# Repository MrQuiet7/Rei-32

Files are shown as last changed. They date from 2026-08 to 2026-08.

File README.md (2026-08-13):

<p align="center">
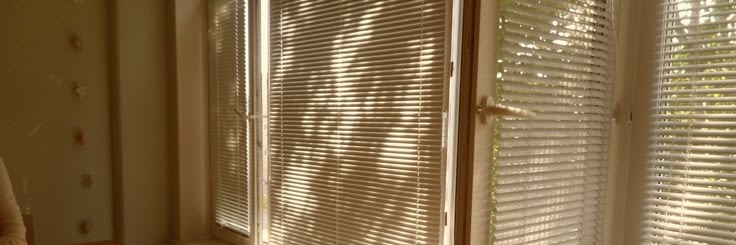
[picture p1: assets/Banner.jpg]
‌Banner
  
</p>

# Rei-32(レイ-32)
### Minimal STM32 Development Board

## Overview

 - A compact STM32 development board designed from scratch with a focus on simplicity, usability, and a clean form factor.
 -  If there’s no need for a feature, it simply isn’t included.
 -  The complete hardware design was created in **KiCad 10**, including the schematic and PCB layout.
 -  **Small board. Simple design. Full control.**

## Features

- STM32 microcontroller
- USB connectivity
- On-board WS2812B addressable LED
- Exposed GPIO pins
- Compact PCB layout
- Open hardware design

## Hardware
- Rei-32 is built around an **STM32F103C8T6** microcontroller, providing an ARM-based platform in a compact and practical form factor.

## Form Factor
- Rei-32 has dimensions of 25mm by 55mm (0.98 inches by 2.17 inches for Americans).

<p align="center">
    PCB  +  Front  +  Front with components  +  Back
</p>

<p align="center">
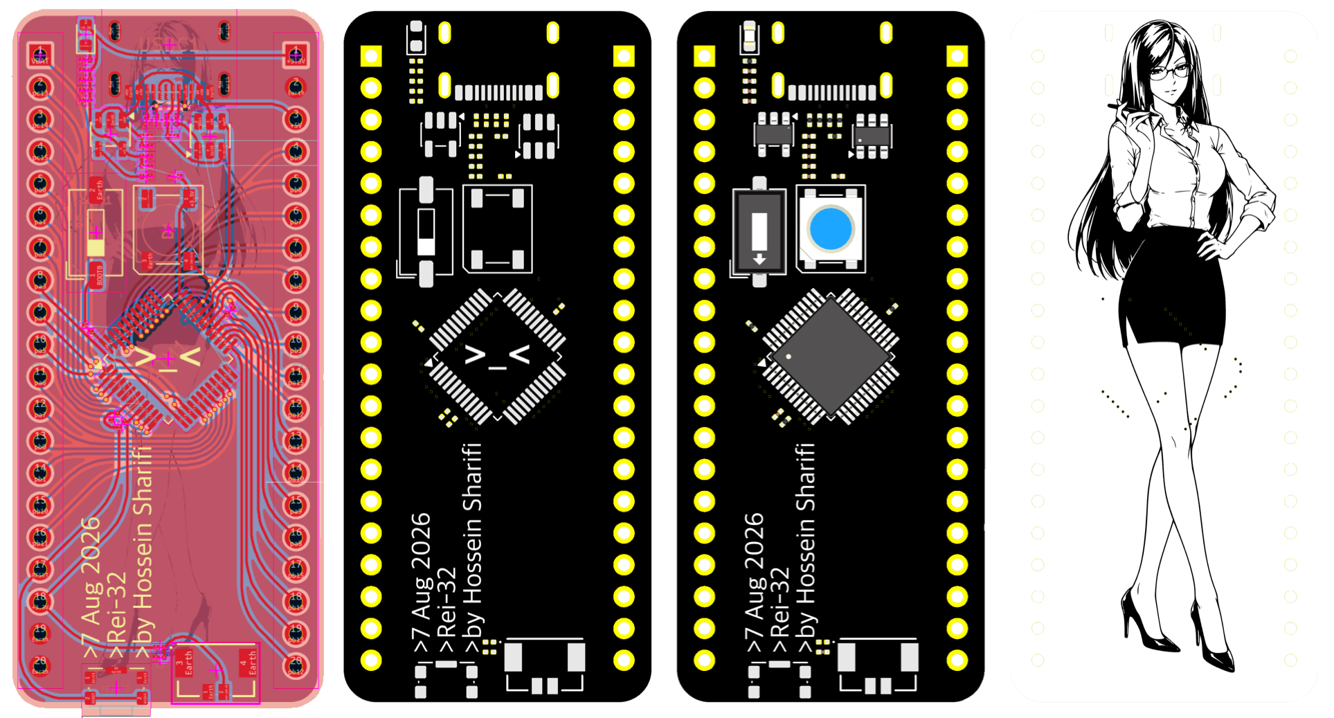
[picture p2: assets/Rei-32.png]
‌レイ-32
  
</p>
- The compact layout allows it to be used in projects where a larger development board would be inconvenient.

## Boot Configuration
- Rei-32 includes dedicated configuration for the STM32 boot modes.
- The boot configuration is accessible directly on the board, allowing the MCU to be placed into the required boot mode without adding external circuitry.

## Status LED
- An addressable WS2812B LED is included on the board.
- It can be used as a simple status indicator or controlled directly by firmware for debugging, state indication, and user feedback.

## Schematic
- The complete schematic is included in the repository.

## Author
- **Hossein Sharifi**
- Designed, developed, and documented as a personal hardware project.

## License
#### GNU General Public License v3.0

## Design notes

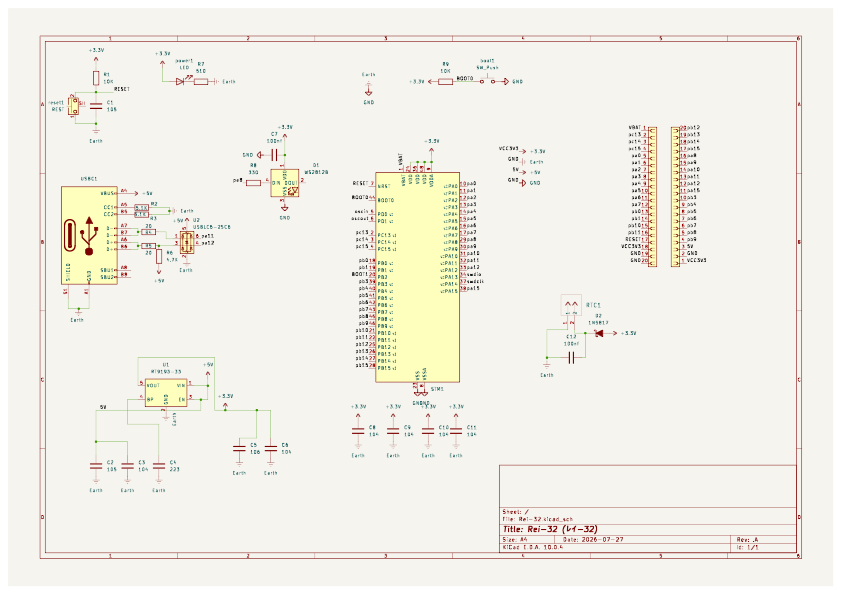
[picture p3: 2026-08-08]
assets/Schematic.png

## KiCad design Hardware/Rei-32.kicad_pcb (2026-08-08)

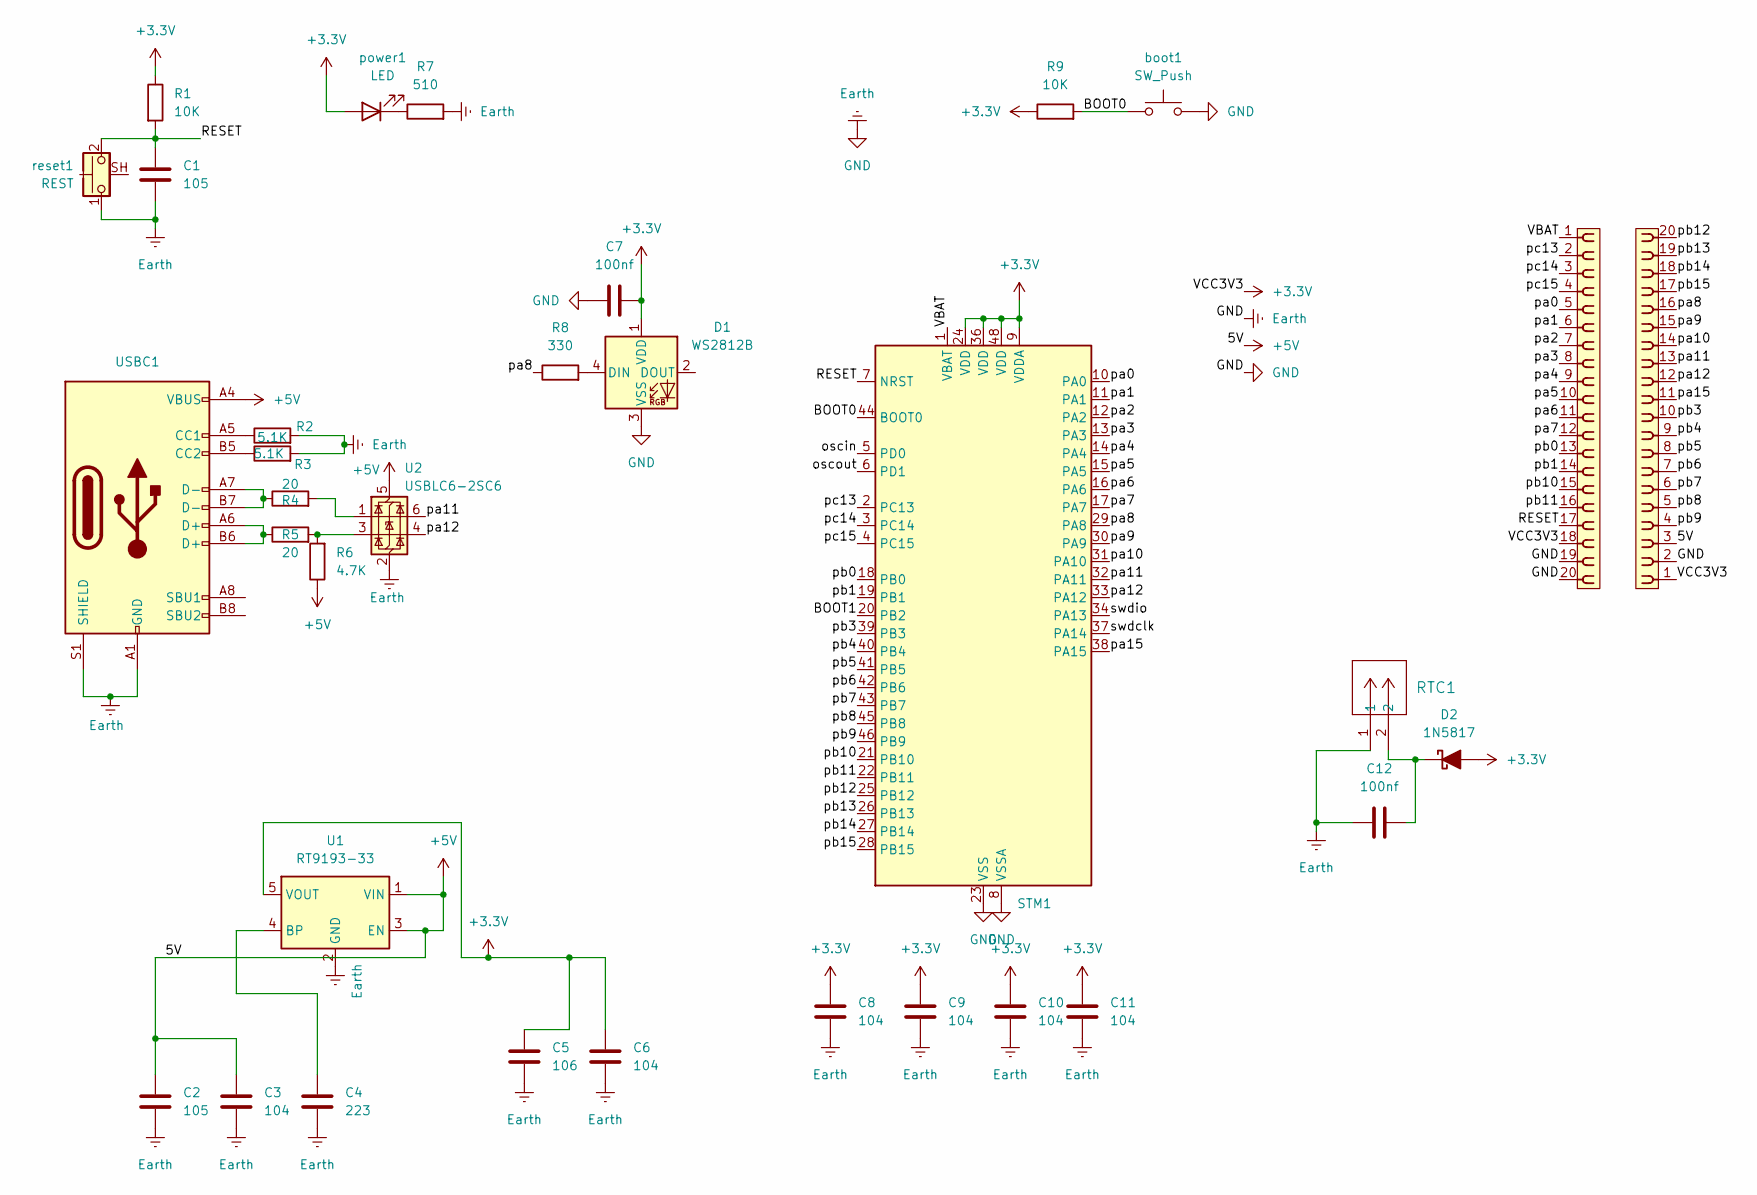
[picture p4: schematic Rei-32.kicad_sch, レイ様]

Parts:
C1, C2: 105; C_0201_0603Metric
C3, C6, C8, C9, C10, C11: 104; C_0201_0603Metric
C4: 223; C_0201_0603Metric
C5: 106; C_0201_0603Metric
C7, C12: 100nf; C_0201_0603Metric
D1: WS2812B; LED_WS2812B_PLCC4_5.0x5.0mm_P3.2mm
D2: 1N5817; D_0201_0603Metric
P1: PINHD_1x20_Female; PinSocket_1x20_P2.54mm_Vertical
R1, R9: 10K; R_0201_0603Metric
R2, R3: 5.1K; R_0201_0603Metric
R4, R5: 20; R_0201_0603Metric
R6: 4.7K; R_0201_0603Metric
R7: 510; R_0201_0603Metric
R8: 330; R_0201_0603Metric
RTC1: CONN_505568_02_MOL
STM1: STM32F103C8Tx; LQFP-48_7x7mm_P0.5mm
U1: RT9193-33; TSOT-23-5
U2: USBLC6-2SC6; SOT-23-6
USBC1: USB_C_Receptacle_USB2.0_16P; USB_C_Receptacle_G-Switch_GT-USB-7010ASV
boot1: SW_Push; SW_DIP_SPSTx01_Slide_6.7x4.1mm_W6.73mm_P2.54mm_LowProfile_J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
p2: PINHD_1x20_Female; PinSocket_1x20_P2.54mm_Vertical
power1: LED; LED_0603_1608Metric
reset1: REST; SW_SPST_CK_KMS2xxG

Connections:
+3.3V: C5.2, C6.2, C7.1, C8.1, C9.1, C10.1, C11.1, D1.1 (VDD), D2.2 (A), P1.18, R1.1, R9.1, STM1.9 (VDDA), STM1.24 (VDD), STM1.36 (VDD), STM1.48 (VDD), U1.5 (VOUT), p2.1, power1.2 (A)
+5V: C2.2, C3.2, R6.1, U1.1 (VIN), U1.3 (EN), U2.5 (VBUS), USBC1.A4 (VBUS), USBC1.A9 (VBUS), USBC1.B4 (VBUS), USBC1.B9 (VBUS), p2.3
/BOOT0: R9.2, STM1.44 (BOOT0), boot1.1
/BOOT1: STM1.20 (PB2)
/RESET: C1.1, P1.17, R1.2, STM1.7 (NRST), reset1.2
/VBAT: P1.1, STM1.1 (VBAT)
/oscin: STM1.5 (PD0)
/oscout: STM1.6 (PD1)
/pa0: P1.5, STM1.10 (PA0)
/pa1: P1.6, STM1.11 (PA1)
/pa2: P1.7, STM1.12 (PA2)
/pa3: P1.8, STM1.13 (PA3)
/pa4: P1.9, STM1.14 (PA4)
/pa5: P1.10, STM1.15 (PA5)
/pa6: P1.11, STM1.16 (PA6)
/pa7: P1.12, STM1.17 (PA7)
/pa8: R8.1, STM1.29 (PA8), p2.16
/pa9: STM1.30 (PA9), p2.15
/pa10: STM1.31 (PA10), p2.14
/pa11: STM1.32 (PA11), U2.6 (I/O1), p2.13
/pa12: STM1.33 (PA12), U2.4 (I/O2), p2.12
/pa15: STM1.38 (PA15), p2.11
/pb0: P1.13, STM1.18 (PB0)
/pb1: P1.14, STM1.19 (PB1)
/pb3: STM1.39 (PB3), p2.10
/pb4: STM1.40 (PB4), p2.9
/pb5: STM1.41 (PB5), p2.8
/pb6: STM1.42 (PB6), p2.7
/pb7: STM1.43 (PB7), p2.6
/pb8: STM1.45 (PB8), p2.5
/pb9: STM1.46 (PB9), p2.4
/pb10: P1.15, STM1.21 (PB10)
/pb11: P1.16, STM1.22 (PB11)
/pb12: STM1.25 (PB12), p2.20
/pb13: STM1.26 (PB13), p2.19
/pb14: STM1.27 (PB14), p2.18
/pb15: STM1.28 (PB15), p2.17
/pc13: P1.2, STM1.2 (PC13)
/pc14: P1.3, STM1.3 (PC14)
/pc15: P1.4, STM1.4 (PC15)
/swdclk: STM1.37 (PA14)
/swdio: STM1.34 (PA13)
Earth: C1.2, C2.1, C3.1, C4.1, C5.1, C6.1, C7.2, C8.2, C9.2, C10.2, C11.2, C12.2, D1.3 (VSS), P1.19, P1.20, R2.2, R3.2, R7.2, RTC1.1, RTC1.3, RTC1.4, STM1.8 (VSSA), STM1.23 (VSS), STM1.35 (VSS), STM1.47 (VSS), U1.2 (GND), U2.2 (GND), USBC1.A1 (GND), USBC1.A12 (GND), USBC1.B1 (GND), USBC1.B12 (GND), USBC1.S1 (SHIELD), USBC1.SH, boot1.2, p2.2, reset1.1, reset1.SH (B)
unnamed: D1.4 (DIN), R8.2
unnamed: C12.1, D2.1 (K), RTC1.2
unnamed: R4.1, USBC1.A7 (D-), USBC1.B7 (D-)
unnamed: R4.2, U2.1 (I/O1)
unnamed: R5.1, USBC1.A6 (D+), USBC1.B6 (D+)
unnamed: R5.2, R6.2, U2.3 (I/O2)
unnamed: C4.2, U1.4 (BP)
unnamed: R2.1, USBC1.A5 (CC1)
unnamed: R3.1, USBC1.B5 (CC2)
unnamed: R7.1, power1.1 (K)

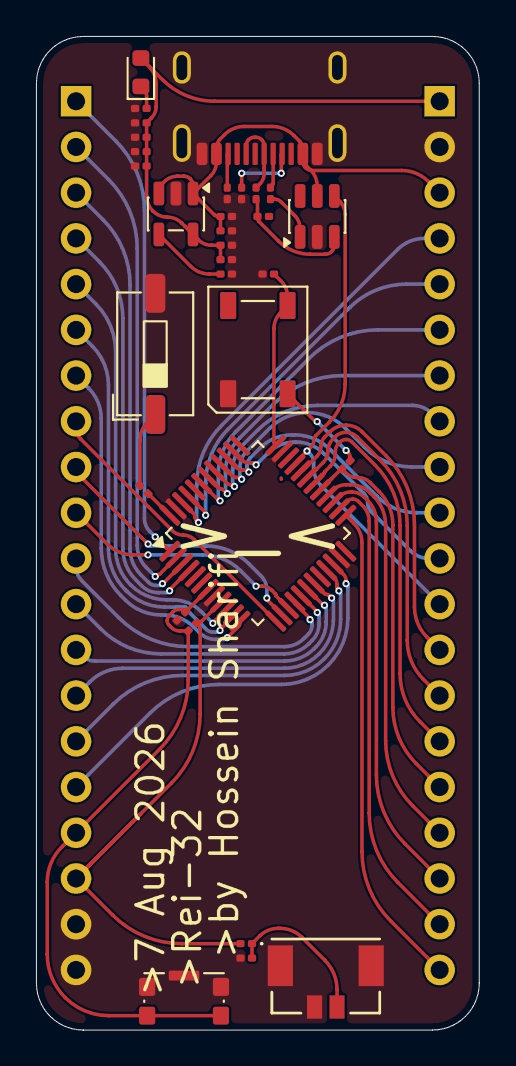
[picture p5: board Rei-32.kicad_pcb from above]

Board: 2 copper layers, 24.6 x 55.2 mm, 33 parts (0 on the bottom side), 48 nets.
